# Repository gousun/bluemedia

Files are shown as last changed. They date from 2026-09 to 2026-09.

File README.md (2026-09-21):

# BlueMedia - BLE 媒体控制旋钮

ESP32 旋钮 + OLED 的蓝牙媒体遥控器：设备把旋转/按键事件通过 BLE 发给 PC 上位机，由上位机模拟按键控制音乐播放、抖音等任何应用。

```
┌──────────────────────────┐       BLE        ┌───────────────────────────┐
│ ESP32 旋钮 + OLED         │ ──事件(EV:*)──▶  │ PC 上位机 (Python/WebView2)│
│ 模式管理 · OLED显示 · LED │ ◀─命令(VOL/MODE)─ │ 按模式映射 → 键盘/鼠标动作  │
└──────────────────────────┘                   └───────────────────────────┘
```

## 目录结构

| 目录 | 内容 | 文档 |
|---|---|---|
| `firmware/` | ESP32 固件（ESP-IDF v5.1.2，NimBLE，模式管理/OLED/编码器） | [firmware/README.md](firmware/README.md) |
| `desktop/` | PC 上位机（Python + pywebview 毛玻璃界面，含自更新） | [desktop/README.md](desktop/README.md) |

> 结构件 CAD/STL 资料在本地 `hardware/` 目录，不入库。

## 功能一览

- **四模式**：音乐控制 / 抖音控制 / 自定义1 / 自定义2，长按旋钮循环切换
- **自定义模式**：名字（同步设备 OLED）+ 手势映射（键盘/鼠标/快捷键）在 GUI 里编辑，配置持久化
- **音乐/抖音控制**：音量、播放暂停、切歌/切视频
- **OLED**：启动动画、模式名、最近事件、音量条、BLE 状态
- **PC 端**：毛玻璃界面（pywebview/WebView2）、系统音量联动、事件日志、**GitHub Releases 自更新**

## 快速开始

**固件**（VSCode ESP-IDF 扩展或命令行，见 firmware/README）：

```bash
cd firmware
idf.py -p COM38 flash monitor
```

**PC 端**：

```bash
cd desktop
pip install -r requirements.txt
python media_gui.py        # 或双击 一键启动.bat
```

## 版本与更新

- PC 端内置自更新：启动时自动检查 GitHub Releases，发现新版本一键下载重启（`desktop/updater.py`）
- 发新版本：改 `desktop/media_core.py` 的 `APP_VERSION` → 运行 `desktop\build_exe.bat <版本号>` → `gh release create vX.Y.Z dist\BlueMedia-vX.Y.Z.zip`
- 注意：自更新依赖 GitHub API，仓库需为 **public**（私有仓库客户端无凭据无法访问）

## 协议

设备/上位机 BLE 协议（FFE0 服务）见 [firmware/README.md](firmware/README.md)。

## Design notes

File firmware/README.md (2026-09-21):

# BlueMedia - BLE 媒体控制器

基于 ESP32-WROOM-32E（4MB Flash）+ ESP-IDF v5.1.2 的蓝牙媒体遥控旋钮。
设备把旋转/按键事件通过 BLE 上报给 PC 上位机（`../blueapp/`），由上位机模拟按键控制音乐播放与抖音。

## 功能

- **BLE 事件上报**（NimBLE，设备名 `BlueMedia`）：旋转/短按/双击/长按事件实时推送给上位机
- **四模式**：音乐控制 / 抖音控制 / 自定义1 / 自定义2；**长按旋钮循环切换**（全局）
- **自定义模式**：名字（≤6字符ASCII）与动作映射在上位机编辑，名字通过 `NAME` 命令同步到设备 OLED，动作映射在上位机执行
- **OLED 显示**（SSD1306 128×64）：开机启动动画；运行页显示当前模式名、最近事件（VOL+/NEXT/PREV…）、音量进度条（上位机回传）、BLE 状态
- **音量回显**：上位机读取 Windows 系统音量后回传设备，OLED 实时显示音量条
- **LED**：BLE 连接指示
- **可扩展**：设备只上报事件，动作映射全部在上位机；自定义模式的名字/映射在 GUI 里即可配置

## 硬件引脚

| 外设 | 引脚 | 说明 |
|---|---|---|
| 板载 LED | GPIO2 | BLE 已连接=亮 |
| 编码器 A/B/按键 | GPIO32 / 33 / 13 | 旋钮+按键 |
| OLED I2C | GPIO21(SDA) / GPIO22(SCL) | SSD1306，地址 0x3C，400kHz |

（早期风扇版遗留的 `components/middlewares/fan`、`dht11` 组件源码保留在仓库，应用不再引用，链接时自动裁剪）

## BLE 协议（FFE0 服务）

- **FFE2 = 通知**（设备 → 上位机，文本事件）
- **FFE1 = 写**（上位机 → 设备，文本命令）

| 事件（FFE2 通知） | 含义 |
|---|---|
| `EV:ROT:+1` / `EV:ROT:-1` | 旋钮右转/左转一格 |
| `EV:KEY:S` | 短按 |
| `EV:KEY:D` | 双击 |
| `EV:MODE:n` | 长按切换模式，n=新模式编号(1起) |

| 命令（FFE1 写入） | 作用 |
|---|---|
| `VOL:<0-100>` | 上位机回报系统音量（OLED 音量条） |
| `MODE:<1-n>` | 上位机直接切换模式 |
| `NAME:<1-n>:<name>` | 同步模式名（自定义槽位 3/4，ASCII ≤6 字符，OLED 显示） |
| `STATUS` | 即时回报状态 JSON `{"mode":1,"name":"MUSIC","vol":35,"volok":1}` |

非法命令回报 `{"err":"CMD"}`。

## 按键判定参数（main/main.c）

| 参数 | 默认 | 含义 |
|---|---|---|
| `BTN_LONG_MS` | 700ms | 按住达到即触发长按（切模式，无需等待释放） |
| `BTN_DOUBLE_MS` | 350ms | 第一次释放后该时间内二次按下判为双击 |

## 工程结构

```
bluefan_esp/
├── CMakeLists.txt / partitions.csv / sdkconfig.defaults
├── main/
│   ├── main.c            app_main + 编码器任务（按键状态机）
│   └── ui.c/h            OLED 启动动画 + 状态页（音符图标程序化绘制）
├── components/
│   ├── bsp/
│   │   ├── led/          GPIO2 LED
│   │   ├── encoder/      旋转编码器（5ms轮询；pressed/released 沿检测）
│   │   └── oled/         SSD1306 驱动 + oled_gfx 帧缓冲图形 API
│   └── middlewares/
│       ├── app_state/    模式/事件/音量/BLE状态（互斥保护，模式名表在此扩展）
│       ├── ble_svc/      NimBLE GATT：事件通知 + VOL/MODE/STATUS 命令
│       ├── fan/          （遗留，未参与应用）
│       └── dht11/        （遗留，未参与应用）
```

### 任务

| 任务 | 周期 | 职责 |
|---|---|---|
| encoder | 5ms | 旋转检测 + 按键状态机 → BLE 事件 |
| ui | 200ms | OLED 渲染、LED 指示 |
| NimBLE host | - | BLE 协议栈（内部任务） |

## 构建与烧录

```bash
cd bluefan_esp
idf.py build
idf.py -p COM38 flash monitor
```

- 命令行构建：本机 `export.bat` 的 cmake 版本自检损坏（cmake 3.24.0 目录实为 3.28.3），可用以下批处理（纯 ASCII）：

```bat
set "MSYSTEM="
set "IDF_PATH=E:\esp32\espidf\Espressif\frameworks\esp-idf-v5.1.2"
set "IDF_TOOLS_PATH=E:\esp32\espidf\Espressif"
set "PATH=%IDF_TOOLS_PATH%\python_env\idf5.1_py3.11_env\Scripts;%IDF_TOOLS_PATH%\tools\cmake\3.24.0\bin;%IDF_TOOLS_PATH%\tools\ninja\1.10.2;%IDF_TOOLS_PATH%\tools\xtensa-esp32-elf\esp-12.2.0_20230208\xtensa-esp32-elf\bin;%PATH%"
cd /d E:\PROJECTS\bluefan_esp32wroom32e\bluefan_esp
python %IDF_PATH%\tools\idf.py build
```

- VSCode ESP-IDF 扩展不受影响，直接 Build & Flash 即可（端口 COM38）

## 上位机

见 `../blueapp/README.md`：`pip install -r requirements.txt` 后运行 `python media_host.py`。

## 新增模式（扩展示例）

1. 固件：`app_state.h` 的 `media_mode_t` 加枚举（如 `MEDIA_MODE_VIDEO`），`app_state.c` 的 `mode_names[]` 加名字，编译烧录
2. 上位机：`media_host.py` 的 `MODES` 加同编号条目，四个动作（`rot_up/rot_down/single/double`）写成本文件中的函数或 lambda

BLE 协议无需改动，OLED 自动显示新模式名与 `M n/总数`。

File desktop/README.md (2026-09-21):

# blueapp - BlueMedia PC 端上位机

配合设备端固件使用：ESP32 旋钮设备把操作事件通过 BLE 发给本程序，本程序按当前模式模拟按键控制 PC。

## 快速开始（一键启动）

**双击 `一键启动.bat`** —— 首次运行自动装依赖，之后直接弹出图形控制台。

也可以手动运行：

```bash
pip install -r requirements.txt
python media_gui.py      # 图形界面（推荐）
python media_host.py     # 控制台版（无界面）
```

## 图形控制台（media_gui.py，pywebview + 毛玻璃界面）

- **外观**：深色玻璃拟态——动态渐变光斑背景、毛玻璃卡片、苹果曲线滑动动画；模式切换用分段控件滑动过渡（视图带模糊淡入）
- **连接状态**：右上角呼吸灯指示，断线自动重连
- **模式切换**：分段控件一键切换（等效长按旋钮），各模式按钮文案自动取自 `media_core.py` 的 `MODES` 表 `ui` 字段
- **系统音量条**：拖动直接设置 Windows 音量（pycaw），旋转旋钮/手动调节后实时同步回显
- **手动动作按钮**：播放/下一首等大按钮按当前模式映射触发，不用旋钮也能操作
- **事件日志**：设备每条事件带时间戳滑入显示（排查问题先看这里）

注意：设备只支持单连接，不要同时开 GUI 和控制台版（或多个实例）。

## 操作说明（设备端）

| 操作 | 音乐模式 | 抖音模式 | 自定义模式×2 |
|---|---|---|---|
| 旋钮右转/左转 | 音量+/音量-（系统音量，全局生效） | 同左 | 由映射决定（默认无） |
| 短按 | 播放/暂停 | 下一个视频 | 由映射决定 |
| 双击 | 下一首 | 暂停/播放（空格键） | 由映射决定 |
| 长按(≥0.7s) | 切换模式（全局，四模式循环） | 同左 | 同左 |

## 自定义模式（槽位 3/4）

GUI 分段控件最后两格（默认名 USER1/USER2），点视图里的 **⚙ 编辑名字与映射**：

- **模式名**：1~6 位英文/数字/符号，保存后自动同步到设备 OLED（受 OLED ASCII 字库限制，不支持中文）
- **手势映射**：短按/双击/旋转↑/旋转↓ 四个手势可分别映射为——常用快捷键（Ctrl+C、Alt+Tab、Win+D…）、媒体键、键盘任意键（点 🎯捕获 后按键录入）、鼠标按键（在光标位置点击）
- **持久化**：保存到 `blueapp/user_modes.json`，GUI 重启自动加载；设备重连时自动把名字重新同步给设备（设备侧名字存 RAM，重启后恢复默认名，由 GUI 自动补同步）
- 未烧录 4 模式固件时设备只有 1/2 两个模式，自定义槽位只在本地生效显示

**注意：**
- 音乐控制用系统媒体键，无需任何窗口前台
- 抖音模式模拟 ↑/↓ 方向键，**抖音窗口（PC 客户端或网页版）必须保持前台焦点**
- 抖音音量默认也用系统媒体键；如需用抖音客户端内置音量，把 `media_core.py` 中 MODES[2] 的 `rot_up/rot_down` 改为 ←/→ 键（文件内注释有说明）
- 短按生效有约 0.25s 延迟（双击判定窗口），属正常

## 功能扩展（加新模式）

1. 固件：`components/middlewares/app_state/app_state.h` 的 `media_mode_t` 加枚举、`app_state.c` 的 `mode_names[]` 加名字，重新编译烧录
2. 上位机：`media_core.py` 的 `MODES` 表加同编号条目（`rot_up/rot_down/single/double` 四个动作），GUI 会自动显示新模式

BLE 协议无需任何改动。

## 文件说明

| 文件 | 用途 |
|---|---|
| `一键启动.bat` | 一键启动 GUI（自动装依赖） |
| `media_gui.py` | 图形控制台宿主（pywebview + JS API 桥） |
| `web/index.html` | 毛玻璃界面（HTML/CSS/JS 单文件） |
| `media_core.py` | 共享核心：BLE 客户端/事件分发/模式映射表（含 `ui` 按钮文案） |
| `media_host.py` | 控制台版客户端 |
| `ble_test.py` | BLE 诊断：`python ble_test.py` 扫描、`--connect` 全链路测试 |
| `ble_listen.py` | BLE 事件监听（诊断用）：`python ble_listen.py` |
| `media_gui_error.log` | GUI 崩溃时自动生成的错误日志 |

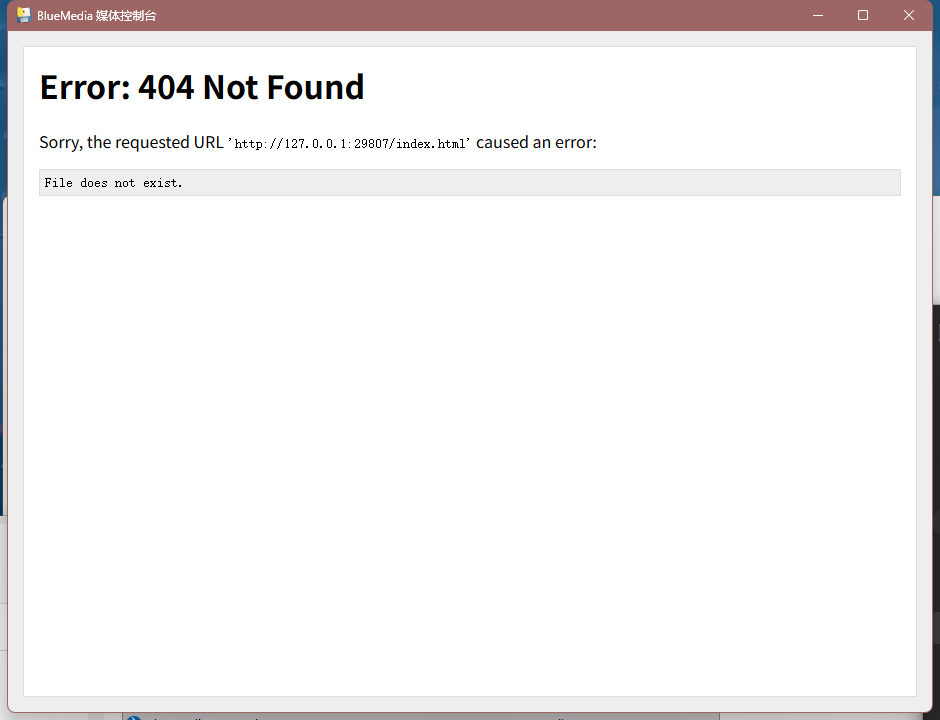
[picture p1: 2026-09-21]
desktop/screenshot.png

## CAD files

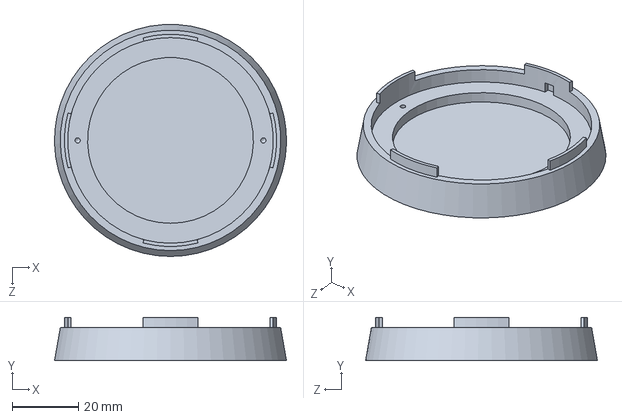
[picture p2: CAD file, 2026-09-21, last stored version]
hardware/零件1.SLDPRT
70.0 x 13.0 x 69.9 mm

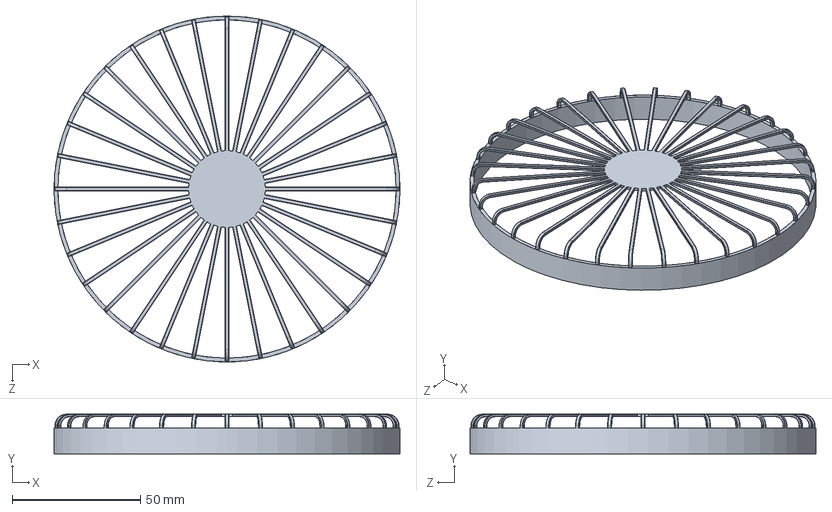
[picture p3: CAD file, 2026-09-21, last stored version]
hardware/fan1.SLDPRT
134.9 x 15.5 x 135.0 mm

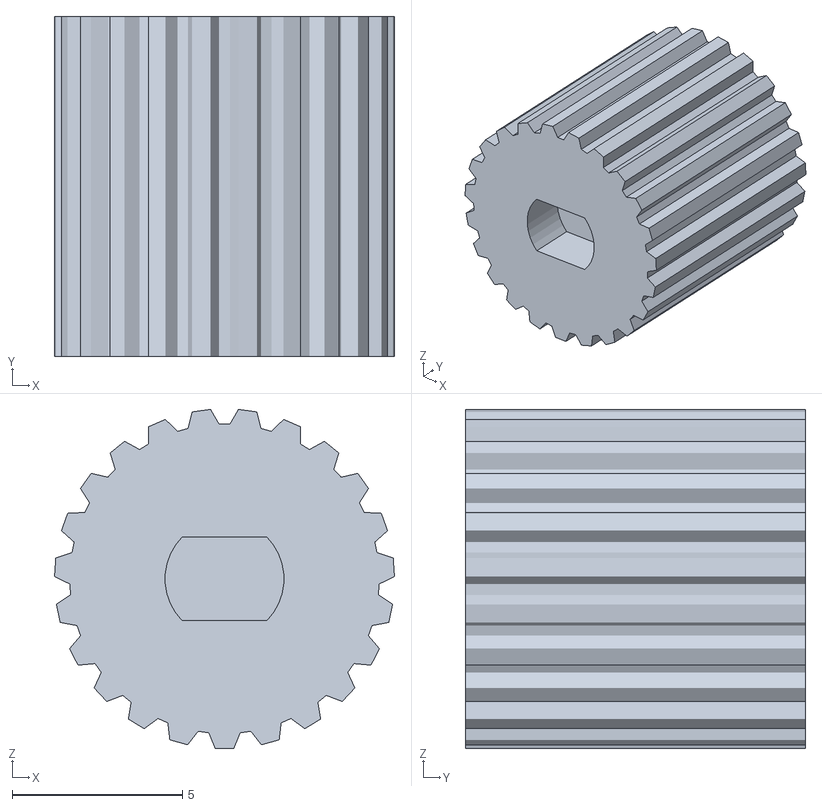
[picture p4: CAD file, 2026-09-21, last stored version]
hardware/零件3.STL
10.00 x 10.0 x 9.98

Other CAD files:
hardware/3d/fan1.STL
hardware/零件1.STL

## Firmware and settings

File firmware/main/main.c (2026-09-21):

/*BlueMedia: BLE 媒体控制器
  旋钮=音量，短按=下一个，双击=上一个，长按=切换模式（音乐/抖音）
  设备只上报事件，具体按键动作由 PC 上位机（blueapp/media_host.py）按模式映射*/

#include <stdbool.h>
#include <stdio.h>
#include "freertos/FreeRTOS.h"
#include "freertos/task.h"
#include "esp_timer.h"
#include "esp_log.h"
#include "led.h"
#include "oled.h"
#include "encoder.h"
#include "app_state.h"
#include "ble_svc.h"
#include "ui.h"

#define BTN_LONG_MS        700    /*长按判定阈值*/
#define BTN_DOUBLE_MS      250    /*双击两次按下最大间隔*/
#define BTN_HOLD_SHORT_MS  400    /*按住>=此值后释放：立即判短按，不进双击窗口
                                    （避免慢速单击被误判为双击的前半段）*/

static const char *BTN_TAG = "btn";
static const char *btn_state_name[] = { "IDLE", "PRESSED", "WAIT2" };

static void send_event(const char *ev, uint8_t app_ev)
{
    app_state_set_event(app_ev);
    ESP_LOGI(BTN_TAG, "send %s", ev);
    ble_svc_notify_event(ev);
}

/*编码器+按键任务（5ms轮询）：
  旋转→EV:ROT; 按键状态机→EV:KEY:S(短按)/EV:KEY:D(双击)/EV:MODE:n(长按)
  长按在按住达到阈值时立即触发（全局模式切换）*/
static void encoder_task(void *arg)
{
    typedef enum { BTN_IDLE, BTN_PRESSED, BTN_WAIT2 } btn_state_t;
    btn_state_t bs = BTN_IDLE;
    int64_t press_t0 = 0, release_t0 = 0, last_beat = 0;
    bool long_fired = false;
    char buf[16];

    while (1)
    {
        int16_t delta = encoder_read();
        if (delta != 0)
        {
            snprintf(buf, sizeof(buf), "EV:ROT:%+d", delta);
            send_event(buf, delta > 0 ? MEDIA_EV_VOL_UP : MEDIA_EV_VOL_DOWN);
        }

        bool pressed = encoder_pressed();
        bool released = encoder_released();
        int64_t now = esp_timer_get_time() / 1000;

        if (pressed)  ESP_LOGI(BTN_TAG, "press edge   state=%s", btn_state_name[bs]);
        if (released) ESP_LOGI(BTN_TAG, "release edge state=%s", btn_state_name[bs]);

        if (now - last_beat >= 5000)    /*心跳：卡死时用于判断本任务是否存活*/
        {
            last_beat = now;
            ESP_LOGI(BTN_TAG, "alive state=%s", btn_state_name[bs]);
        }

        switch (bs)
        {
        case BTN_IDLE:
            if (pressed)
            {
                bs = BTN_PRESSED;
                press_t0 = now;
                long_fired = false;
            }
            break;

        case BTN_PRESSED:
            if (!long_fired && now - press_t0 >= BTN_LONG_MS)
            {
                long_fired = true;
                app_state_cycle_mode();                 /*长按：切换模式（全局）*/
                app_state_t st;
                app_state_get(&st);
                snprintf(buf, sizeof(buf), "EV:MODE:%u", (unsigned)(st.mode + 1));
                send_event(buf, MEDIA_EV_MODE);
            }
            if (released)
            {
                if (long_fired)
                {
                    bs = BTN_IDLE;                      /*长按已触发，忽略本次释放*/
                }
                else if (now - press_t0 >= BTN_HOLD_SHORT_MS)
                {
                    send_event("EV:KEY:S", MEDIA_EV_NEXT);    /*按住较久的单击：立即生效*/
                    bs = BTN_IDLE;
                }
                else
                {
                    release_t0 = now;
                    bs = BTN_WAIT2;
                }
            }
            break;

        case BTN_WAIT2:    /*第一次已释放，等待可能的第二次按下*/
            if (pressed)
            {
                bs = BTN_PRESSED;                       /*双击确认；第二击按住不再触发长按*/
                press_t0 = now;
                long_fired = true;
                send_event("EV:KEY:D", MEDIA_EV_PREV);
            }
            else if (now - release_t0 >= BTN_DOUBLE_MS)
            {
                send_event("EV:KEY:S", MEDIA_EV_NEXT);  /*超时无第二击=短按*/
                bs = BTN_IDLE;
            }
            break;

        default:
            bs = BTN_IDLE;
            break;
        }

        vTaskDelay(pdMS_TO_TICKS(5));    //编码器扫描需<=10ms周期
    }
}

void app_main(void)
{
    led_init();
    led(0);

    app_state_init();
    OLED_Init();
    encoder_init();
    ble_svc_init();

    xTaskCreate(encoder_task, "encoder", 3072, NULL, 6, NULL);
    xTaskCreate(ui_task, "ui", 4096, NULL, 4, NULL);
}

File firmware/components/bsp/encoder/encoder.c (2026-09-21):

#include "encoder.h"
#include "driver/gpio.h"
#include "freertos/FreeRTOS.h"
#include "freertos/task.h"

#define ENC_A_GPIO     GPIO_NUM_32
#define ENC_B_GPIO     GPIO_NUM_33
#define ENC_SW_GPIO    GPIO_NUM_13

#define ENC_ROT_DEBOUNCE_MS     10   //AB线软件消抖
#define ENC_SW_DEBOUNCE_MS      40   //按键软件消抖（过短会把按住中的接触噪声误判为释放沿）

/*正交解码表，index = (prev_ab << 2) | curr_ab，ab = (A << 1) | B*/
static const int8_t enc_table[16] = {
    0, -1,  1,  0,
    1,  0,  0, -1,
   -1,  0,  0,  1,
    0,  1, -1,  0
};

static uint8_t enc_stable;          //消抖后的稳定状态
static uint8_t enc_cand;            //候选状态
static TickType_t enc_cand_since;   //候选状态首次出现时刻
static int8_t enc_step_acc;         //跳变累计，满2个=一格

static bool sw_candidate;
static bool sw_stable;              //true=未按下(高), false=按下(低)
static TickType_t sw_last_change;

static inline uint8_t enc_read_ab(void)
{
    return (uint8_t)((gpio_get_level(ENC_A_GPIO) << 1) | gpio_get_level(ENC_B_GPIO));
}

void encoder_init(void)
{
    gpio_config_t io = {
        .pin_bit_mask = (1ULL << ENC_A_GPIO) | (1ULL << ENC_B_GPIO) | (1ULL << ENC_SW_GPIO),
        .mode = GPIO_MODE_INPUT,
        .pull_up_en = GPIO_PULLUP_ENABLE,
        .pull_down_en = GPIO_PULLDOWN_DISABLE,
        .intr_type = GPIO_INTR_DISABLE,
    };
    gpio_config(&io);

    enc_stable = enc_read_ab();
    enc_cand = enc_stable;
    enc_cand_since = xTaskGetTickCount();
    enc_step_acc = 0;

    sw_stable = (bool)gpio_get_level(ENC_SW_GPIO);
    sw_candidate = sw_stable;
    sw_last_change = xTaskGetTickCount();
}

int16_t encoder_read(void)
{
    uint8_t raw = enc_read_ab();
    TickType_t now = xTaskGetTickCount();

    if (raw != enc_cand)
    {
        enc_cand = raw;
        enc_cand_since = now;
    }
    else if (raw != enc_stable &&
             (now - enc_cand_since) >= pdMS_TO_TICKS(ENC_ROT_DEBOUNCE_MS))
    {
        int8_t step = enc_table[(uint8_t)((enc_stable << 2) | enc_cand)];
        enc_stable = enc_cand;

        if (step != 0)
        {
            enc_step_acc += step;
            if (enc_step_acc >= 2 || enc_step_acc <= -2)   //满2个跳变=一格
            {
                enc_step_acc = 0;
                return (step > 0) ? 1 : -1;
            }
        }
    }
    return 0;
}

/*按键按下沿（低电平有效）。只处理"按下"方向的翻转；
  松开方向的消抖与翻转由 encoder_released() 负责，避免共享stable时互相偷沿*/
bool encoder_pressed(void)
{
    if (gpio_get_level(ENC_SW_GPIO)) return false;    //高=未按下，本函数不参与
    bool raw = false;
    TickType_t now = xTaskGetTickCount();

    if (raw != sw_candidate)
    {
        sw_candidate = raw;
        sw_last_change = now;
        return false;
    }
    if (sw_stable && (now - sw_last_change) >= pdMS_TO_TICKS(ENC_SW_DEBOUNCE_MS))
    {
        sw_stable = false;
        return true;    //按下沿
    }
    return false;
}

/*按键释放沿（高电平）。只处理"释放"方向的翻转*/
bool encoder_released(void)
{
    if (!gpio_get_level(ENC_SW_GPIO)) return false;   //低=按住中，本函数不参与
    bool raw = true;
    TickType_t now = xTaskGetTickCount();

    if (raw != sw_candidate)
    {
        sw_candidate = raw;
        sw_last_change = now;
        return false;
    }
    if (!sw_stable && (now - sw_last_change) >= pdMS_TO_TICKS(ENC_SW_DEBOUNCE_MS))
    {
        sw_stable = true;
        return true;    //释放沿
    }
    return false;
}

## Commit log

2026-09-21 Initial commit: BlueMedia BLE media controller
    - firmware/: ESP32-WROOM-32E firmware (ESP-IDF v5.1.2, NimBLE, 4 modes, OLED, encoder)
    - desktop/: PC desktop app (pywebview glass UI, mode mapping editor, GitHub self-update)
    - hardware/: 3D/CAD parts
    [fan1.SLDPRT, fan1.STL, partitions.csv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]
2026-09-21 chore: exclude hardware CAD folder from repo
    [fan1.SLDPRT, fan1.STL, 零件1.SLDPRT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]
